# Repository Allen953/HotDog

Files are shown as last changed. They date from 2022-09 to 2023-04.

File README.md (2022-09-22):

# HotDog
HotDog is a open source quadruped robot.

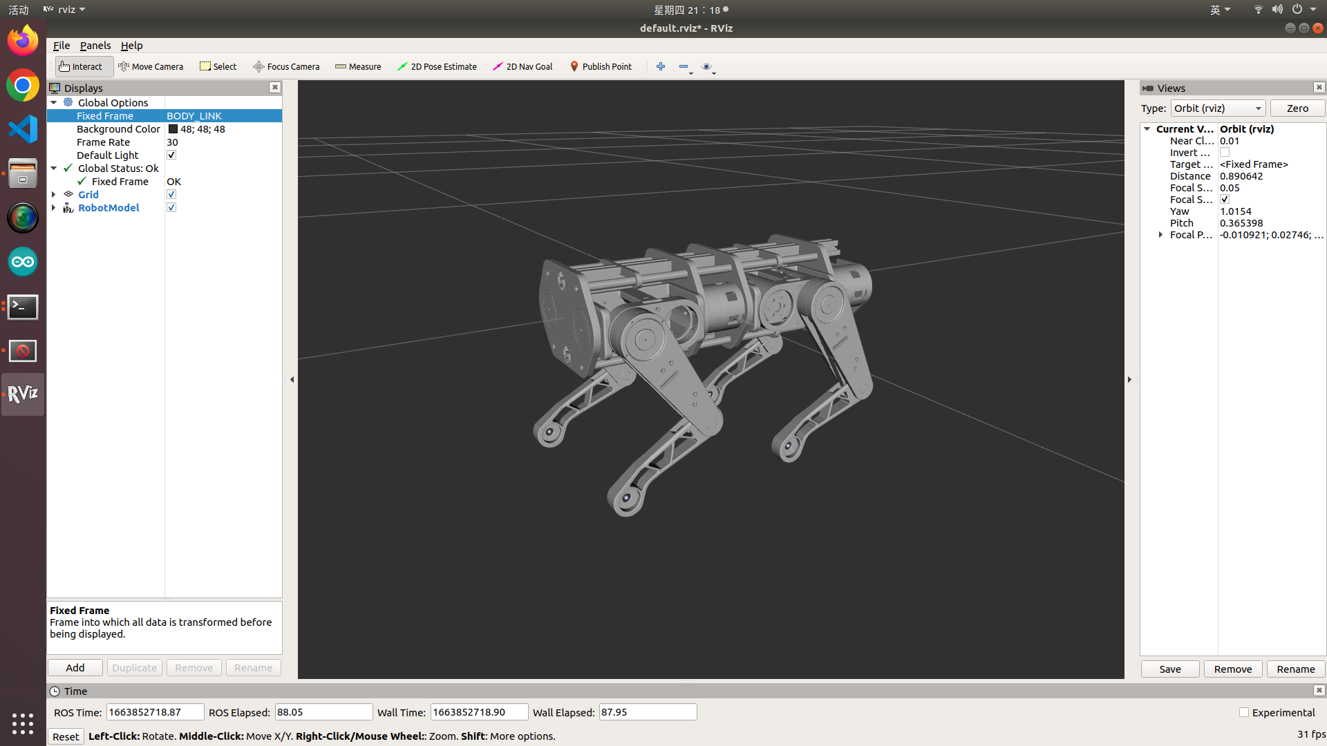
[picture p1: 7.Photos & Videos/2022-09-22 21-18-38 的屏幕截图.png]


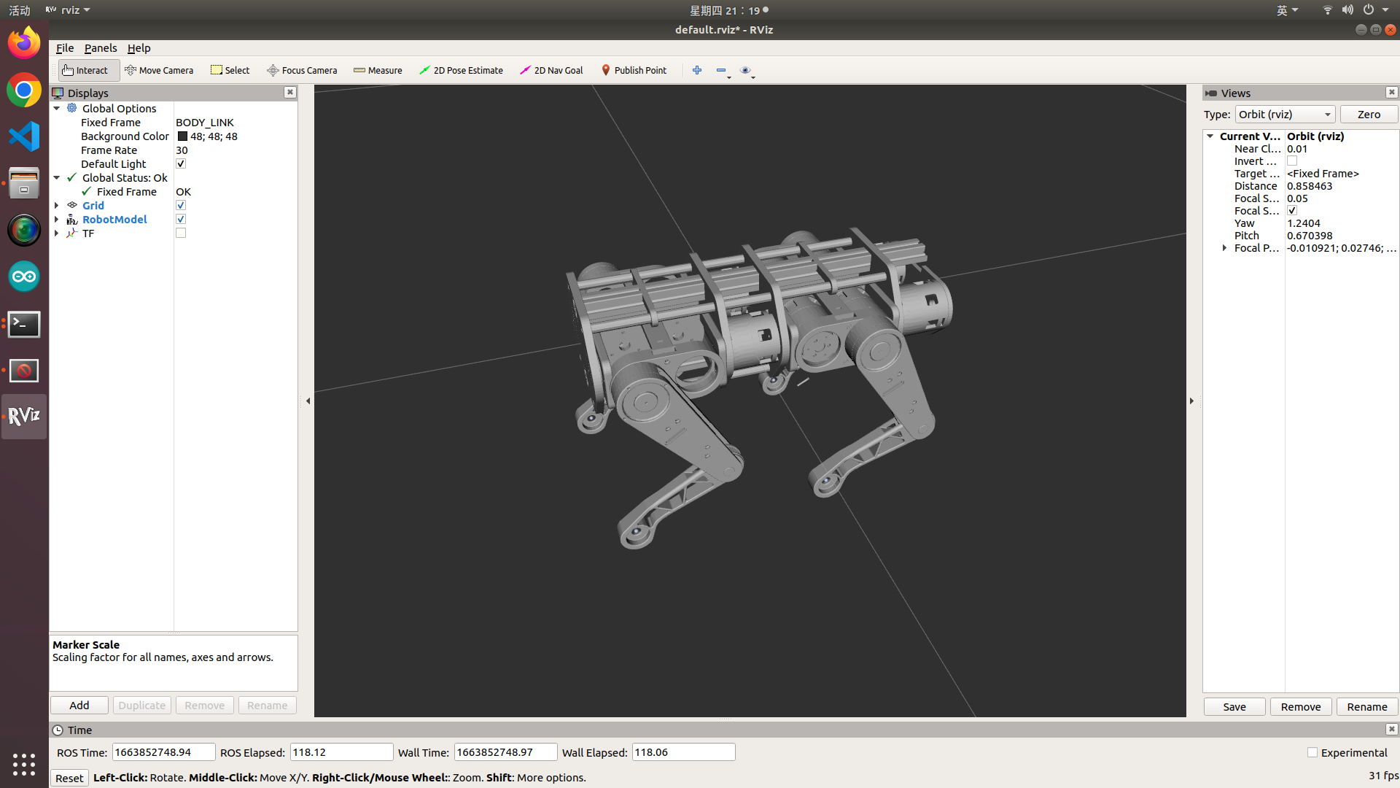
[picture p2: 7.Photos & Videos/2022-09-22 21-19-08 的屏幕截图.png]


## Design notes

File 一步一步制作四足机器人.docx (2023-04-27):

分类号 | TP242 | | | | 学校代码 | 10590
UDC | 621 | | | | 密 级 | 公开

一步一步制作四足机器人

刘志通

学 位 类 别 | 工程硕士专业学位
专 业 名 称 | 机械
学院（系、所） | 机电与控制工程学院
指 导 教 师 | 杜建铭 教授

# 第1章 四足机器人结构制作

## 1.1 引言

四足机器人的结构是实现控制系统的基础，本章首先介绍了本课题设计的四足机器人的结构，接着基于该四足机器人的模型参数，对其进行运动学和动力学建模及分析。

## 1.2 四足机器人结构组装

### 1.2.1 功能需求分析

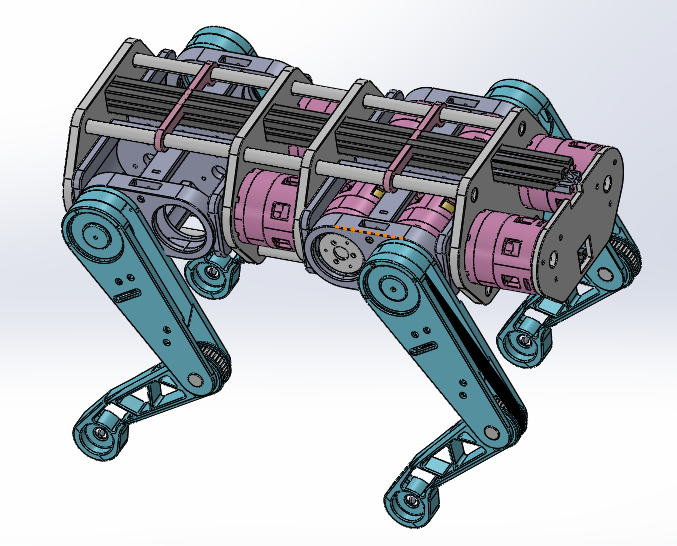
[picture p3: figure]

图1-1

机器人模型如图1-1所示，

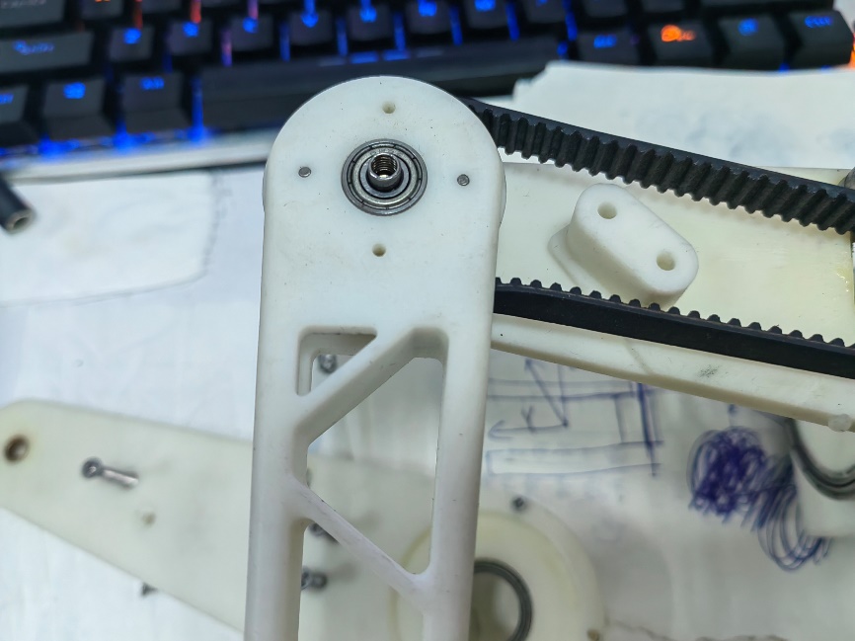
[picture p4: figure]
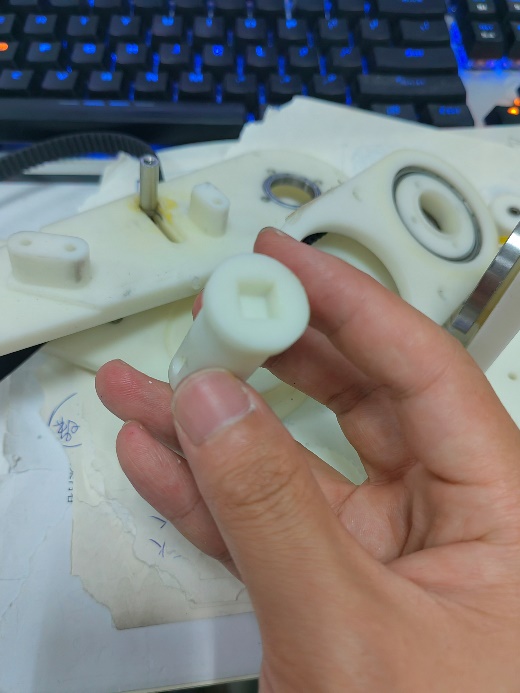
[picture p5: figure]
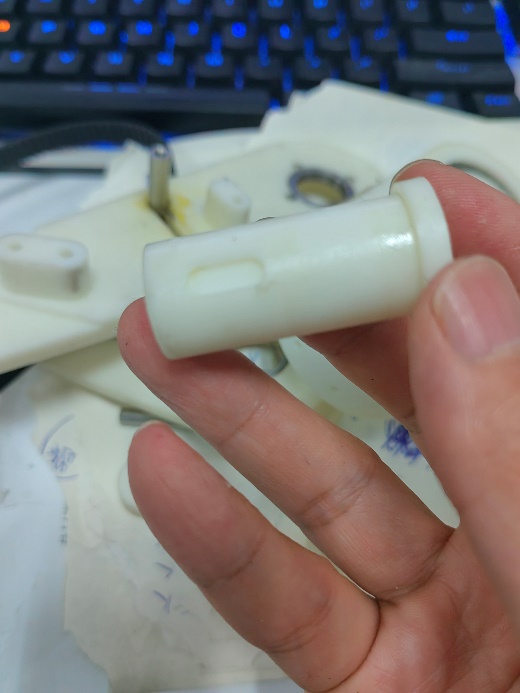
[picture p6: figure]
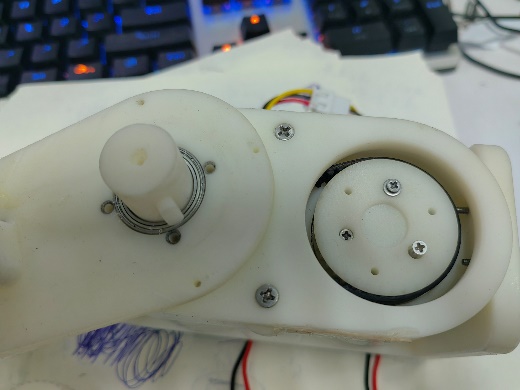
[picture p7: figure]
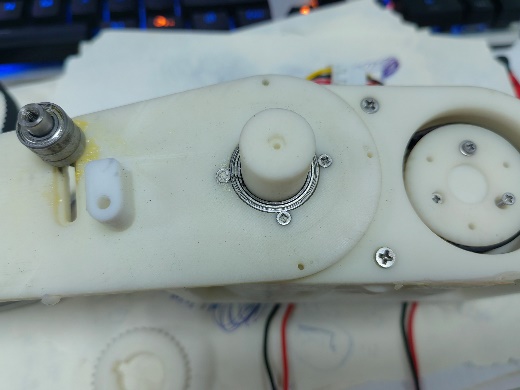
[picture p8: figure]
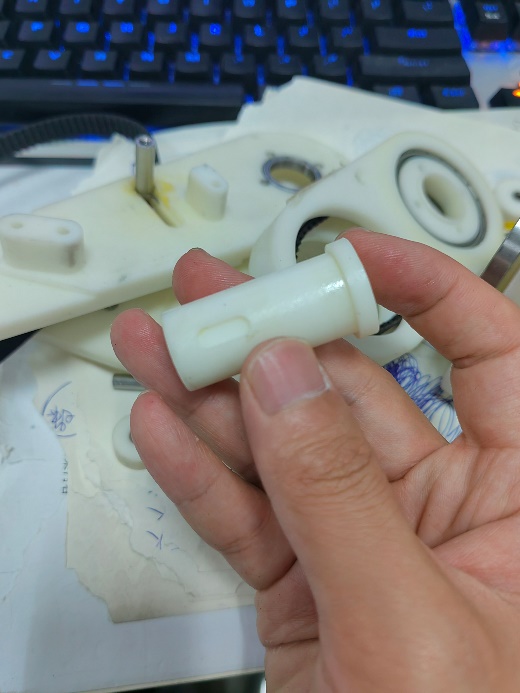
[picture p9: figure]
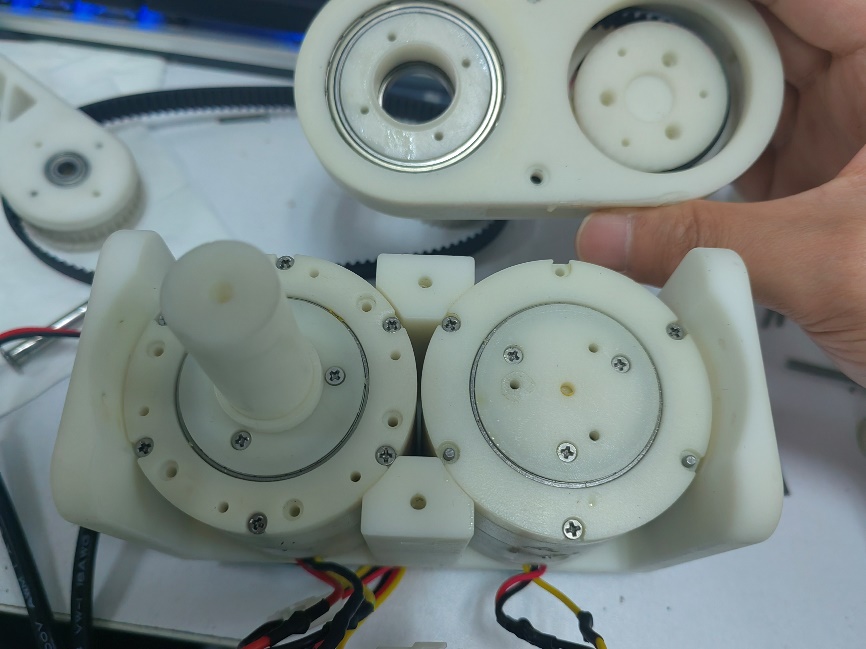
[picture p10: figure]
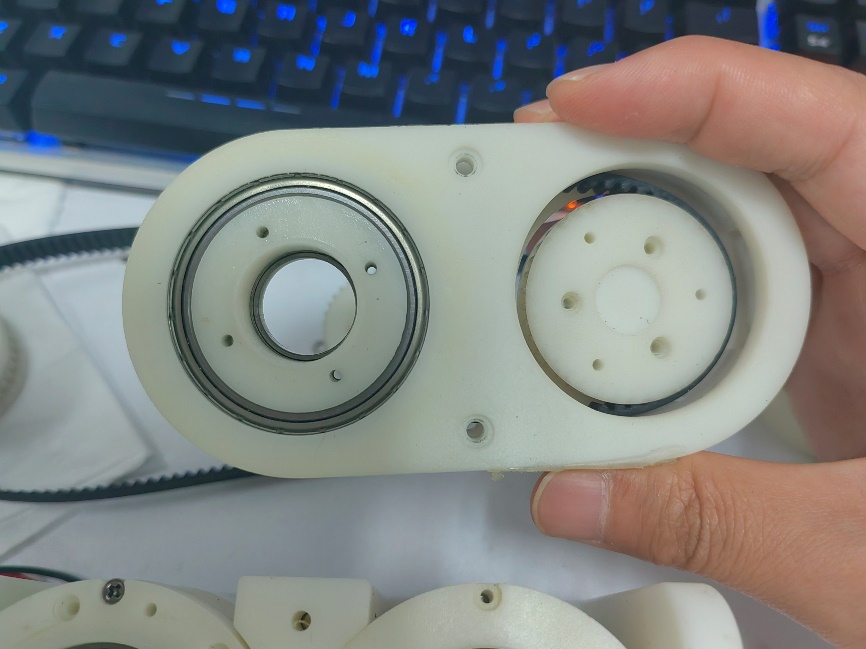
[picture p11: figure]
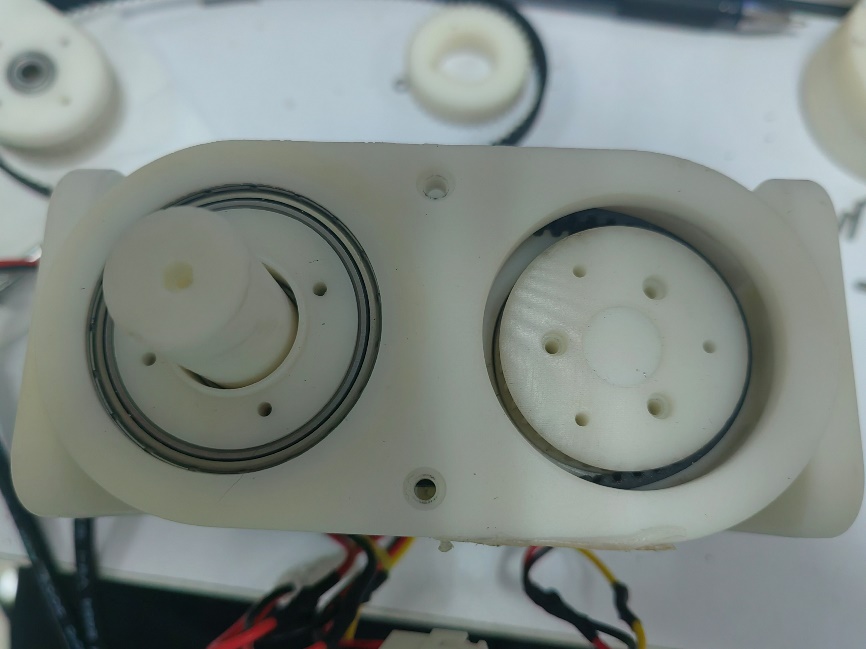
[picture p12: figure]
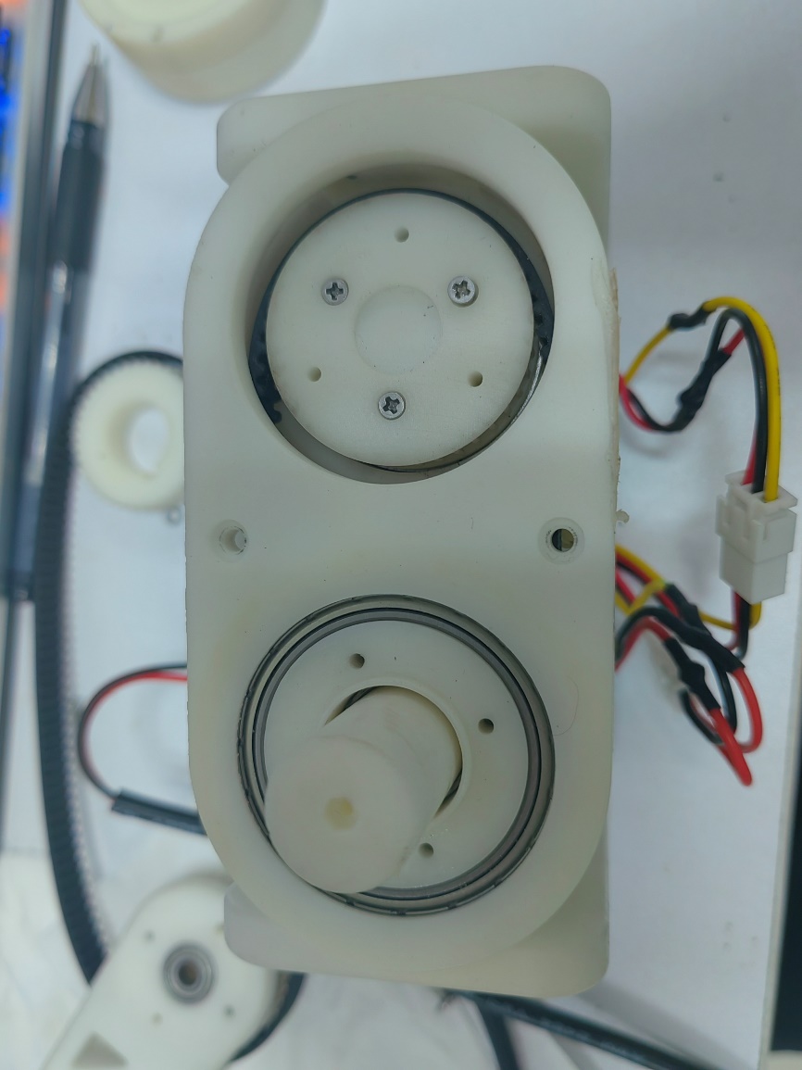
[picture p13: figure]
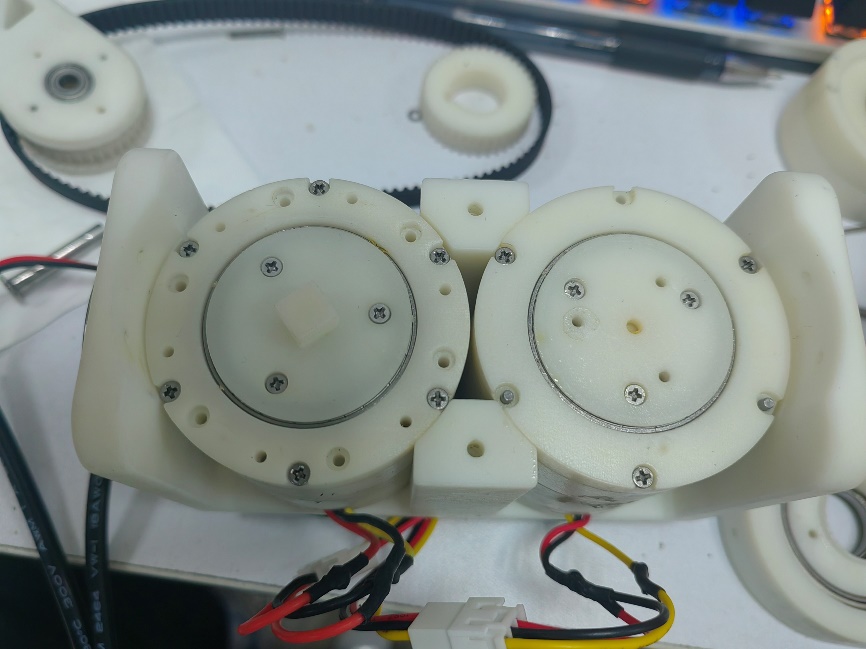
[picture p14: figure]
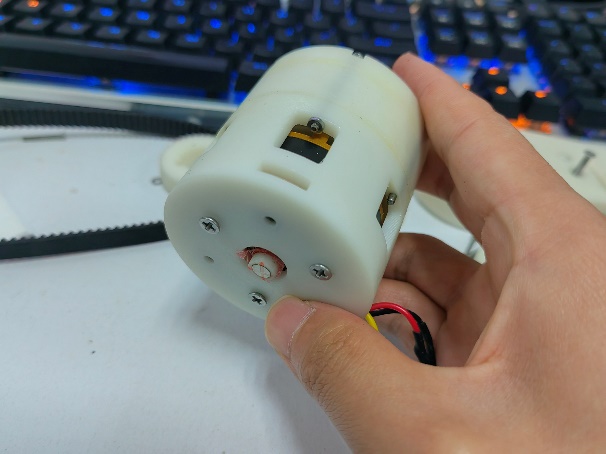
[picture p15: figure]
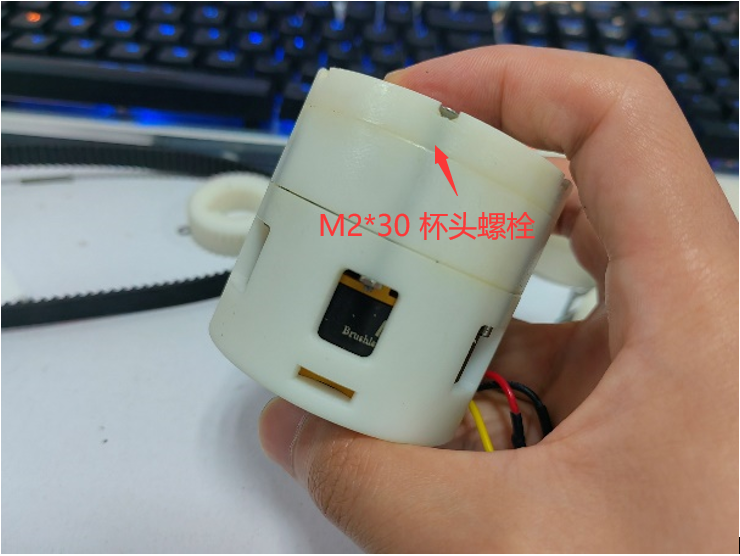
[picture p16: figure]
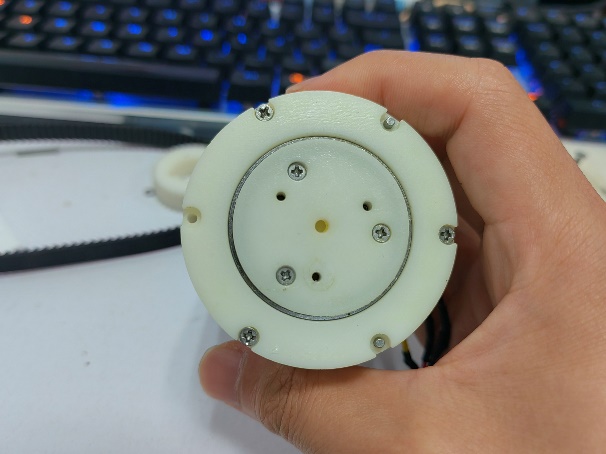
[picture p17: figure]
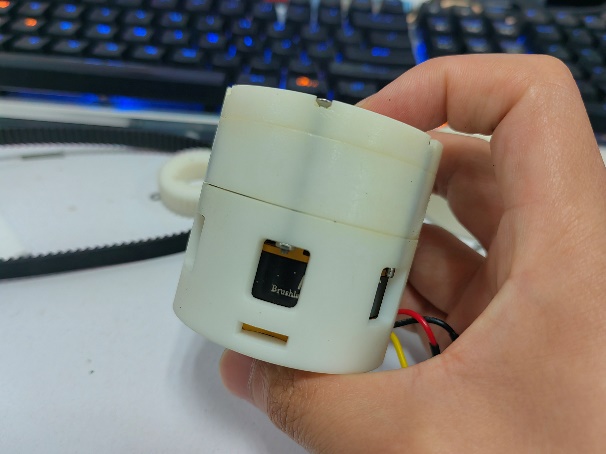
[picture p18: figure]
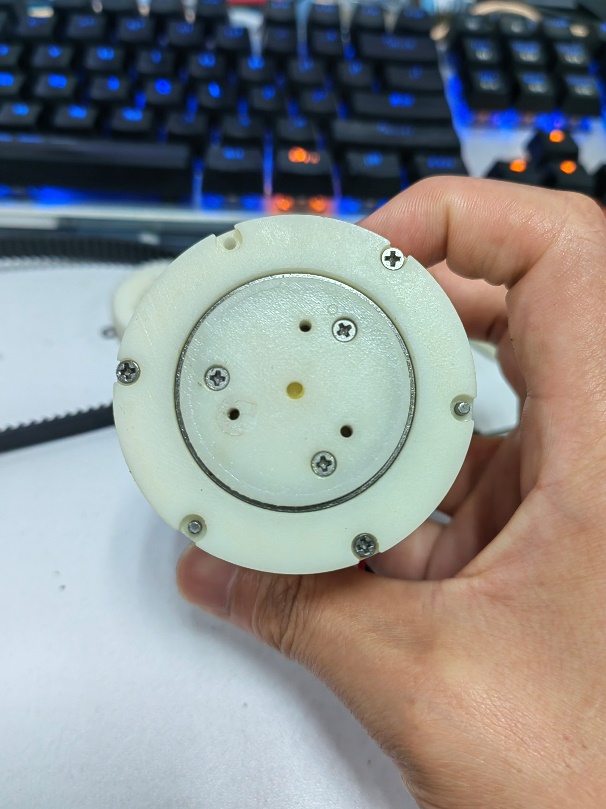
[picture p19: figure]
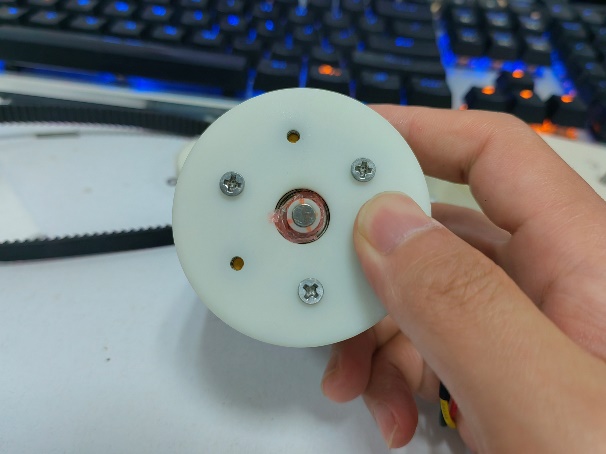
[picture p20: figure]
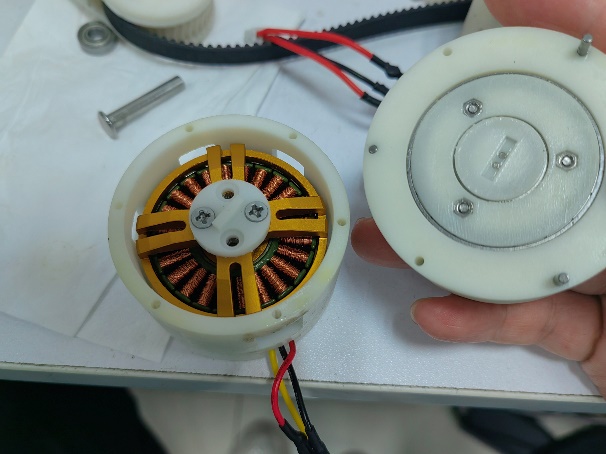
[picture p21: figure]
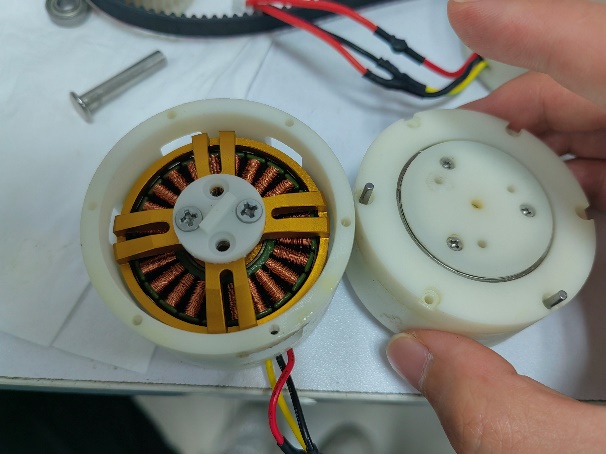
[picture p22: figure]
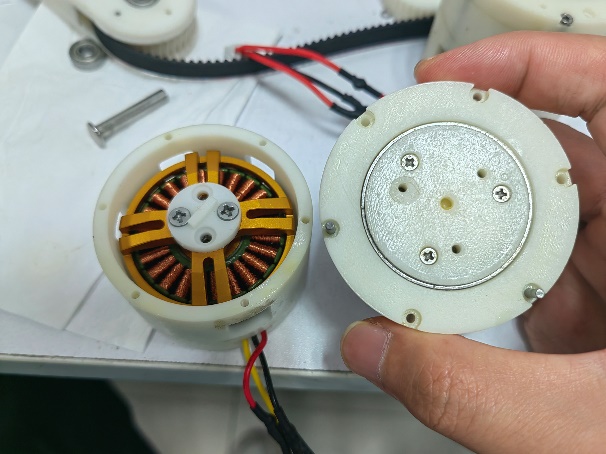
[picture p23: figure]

一个减速器需要用到的标准件：

轴承：

内30外37高4 2个

内12外18高4 1个

内8外14高4 2个

内5外11高4 1个

圆柱销：φ6*12 10个

圆柱销：φ2*18 3个

最终是一个二次型的形式，这个形式是

# 第2章 基于机器人关节学习SimpleFoc算法

## 2.1 引言

软件系统是控制系统中的核心，本章实现四足机器人ROS平台下的分布式软件系统设计。本章将分析设计软件系统架构，并基于控制软件需求设计各个核心程序，完成整个软件系统搭建。

## 2.2 SimpleFoc控制模型及流程

## 2.3 SimpleFoc实践讨论

打开HotDog项目下如下例程，研究电机的力矩控制

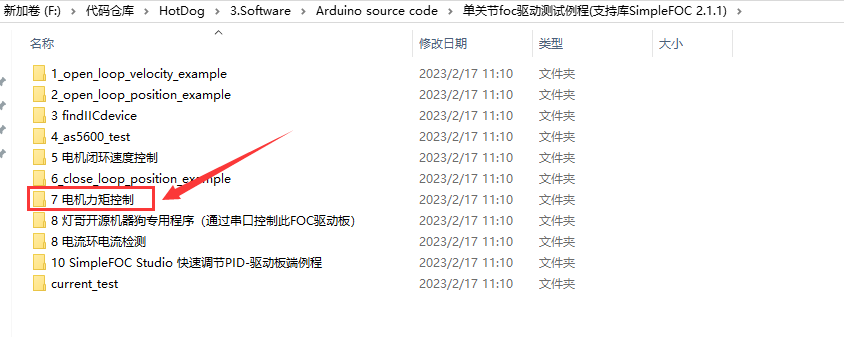
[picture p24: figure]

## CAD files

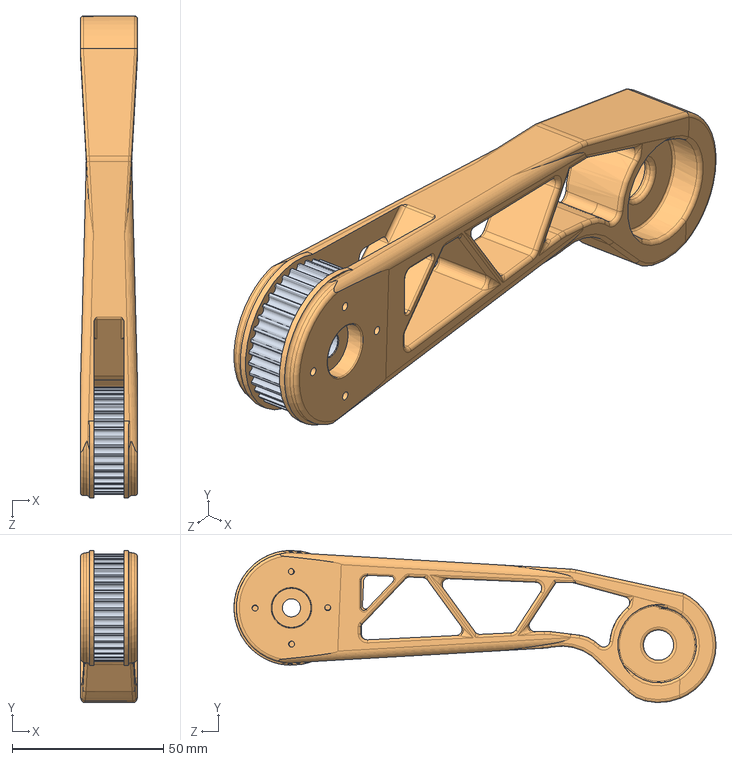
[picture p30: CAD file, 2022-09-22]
1.3D model/HotDog/RB_SHANK_LINK.SLDASM
19.0 x 50.3 x 159.4 mm
同步轮
小足

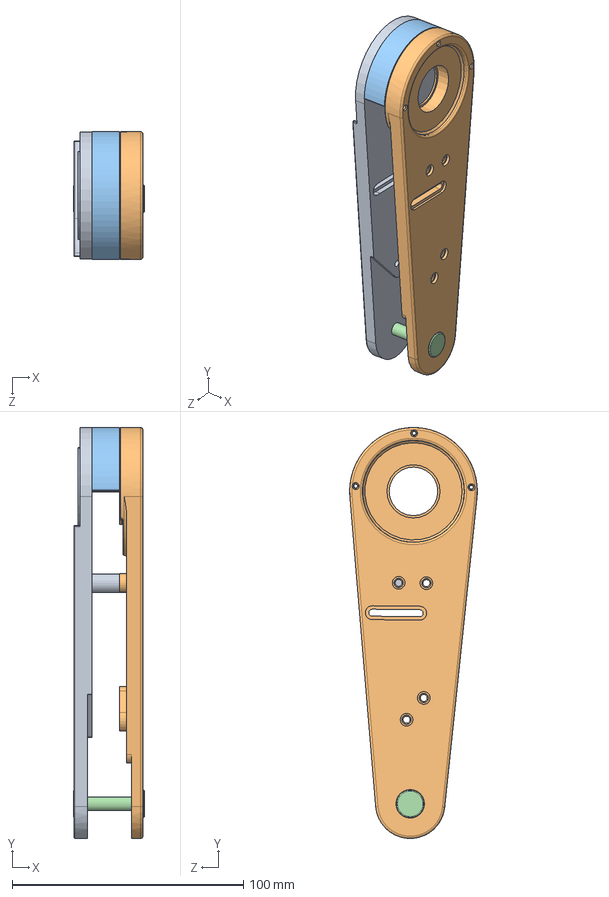
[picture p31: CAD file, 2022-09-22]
1.3D model/HotDog/RB_THIGH_LINK.SLDASM
30.6 x 177.6 x 55.2 mm
大足
大足2
支撑半环
字母钉

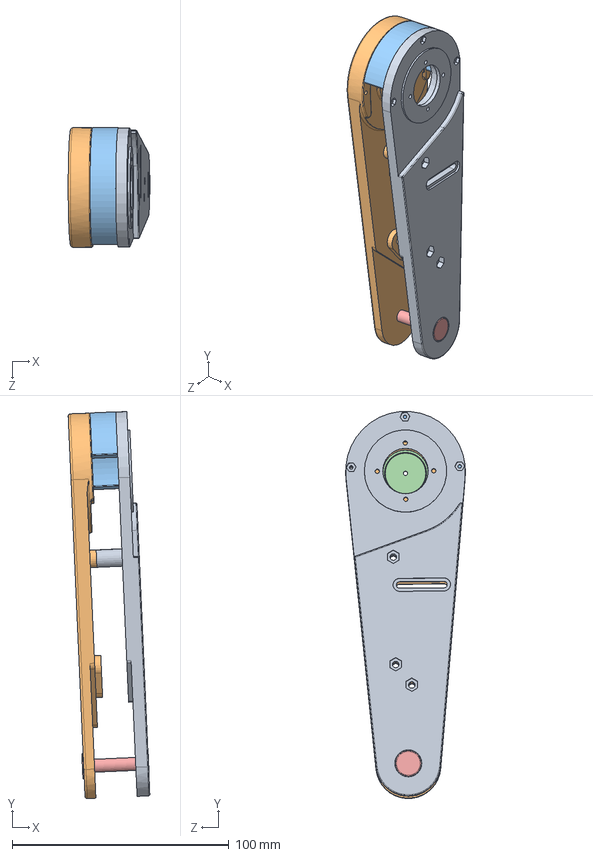
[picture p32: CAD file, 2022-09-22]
1.3D model/HotDog/LF_THIGH_LINK.SLDASM
37.6 x 178.4 x 55.2 mm
大足
大足2
支撑半环
端盖
字母钉

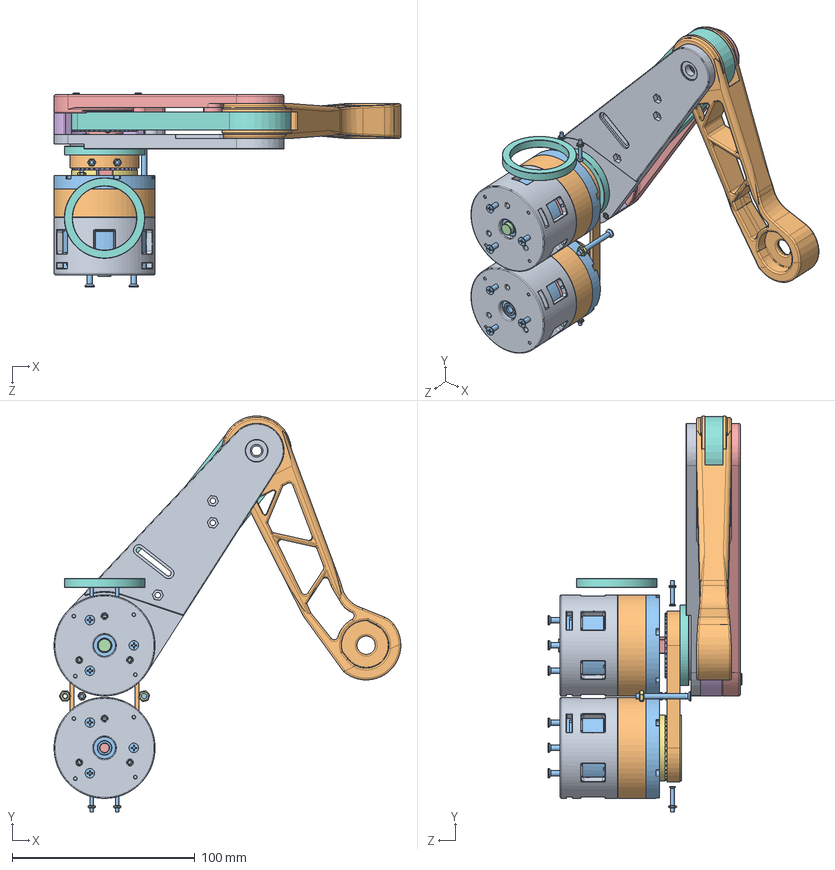
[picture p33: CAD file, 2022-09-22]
1.3D model/HotDog/关节5_0版本.SLDASM
189.6 x 216.4 x 105.8 mm
电机座 x 2
减速器壳体 x 2
30-37-4轴承6 x 2
输出轴 x 2
减速器上盖
光杆同步轮10
17-23-4轴承 x 3
35-44-5轴承 x 2
大足
小足
光杆同步轮
键
大足2
同步轮
张紧轮
端盖
cross countersunk head screw_as x 4
cross recessed countersunk head screws gb1 x 16
hex thin nuts-grades ab-chamfered gb x 4
定位环
支撑半环
hex nuts, style 1-grades ab gb x 6
同步带
定位环_17_20_1-2mm
同步带168
电机46 x 2
磁铁

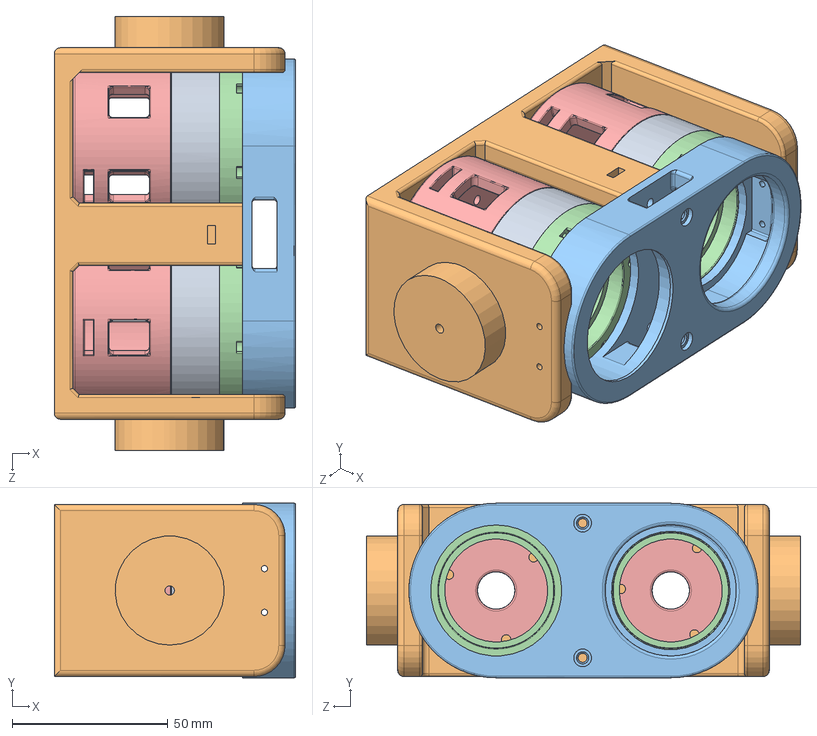
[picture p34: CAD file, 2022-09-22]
1.3D model/HotDog/RB_JIAN_LINK.SLDASM
77.4 x 56.0 x 139.2 mm
减速器壳体 x 2
支撑架
保持架
减速器上盖 x 2
电机座 x 2

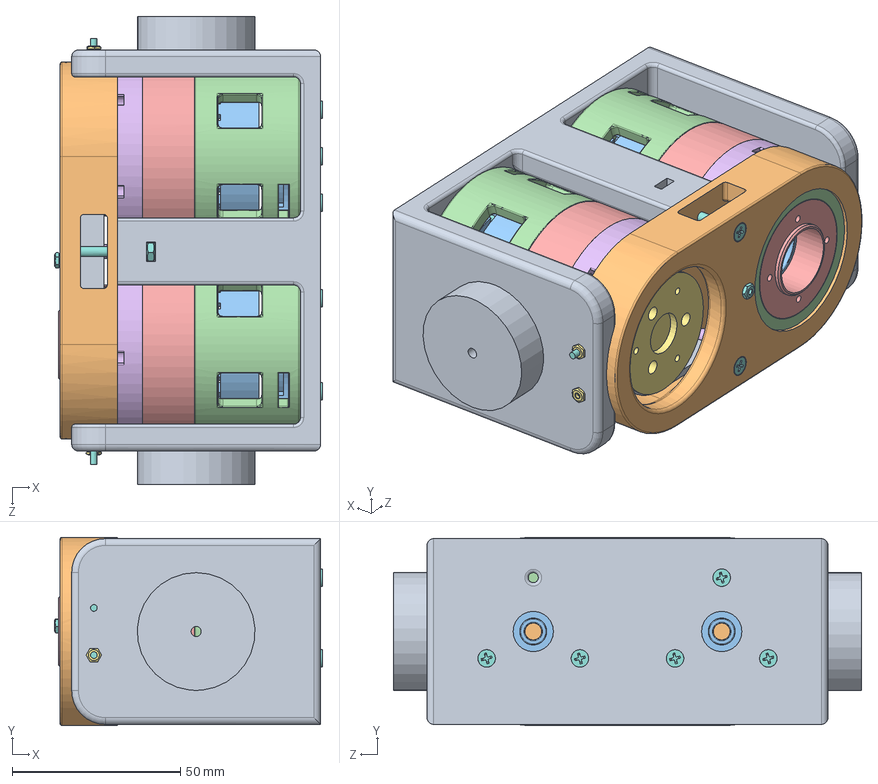
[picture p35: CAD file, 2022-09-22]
1.3D model/HotDog/LB_JIAN_LINK.SLDASM
79.7 x 56.0 x 139.2 mm
支撑架
保持架
电机46 x 2
电机座 x 2
减速器壳体 x 2
减速器上盖 x 2
cross recessed countersunk head screws gb1 x 14
30-37-4轴承6 x 2
输出轴 x 2
17-23-4轴承
35-44-5轴承
光杆同步轮10
张紧轮
hex thin nuts-grades ab-chamfered gb x 3
hex nuts, style 1-grades ab gb x 4
同步带168

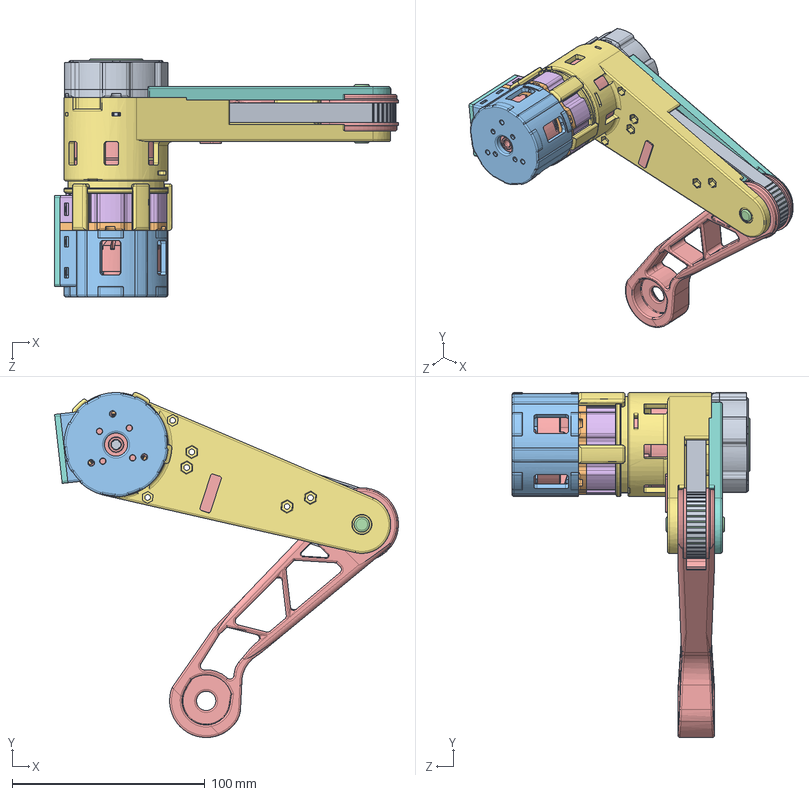
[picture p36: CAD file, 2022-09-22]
1.3D model/HotDog/Cycloid_Reducer.SLDASM
178.4 x 178.9 x 123.3 mm
机壳
轴承20_27_4 x 4
M6x10销钉 x 10
Output_Shaft2
M2x18销钉 x 5
定位中间件 x 2
轴承8_16_4
传动曲轴_2 x 2
轴承10_15_4 x 2
摆线轮1
摆线轮2
M1.5x14销轴 x 2
无刷电机 x 2
AS5600 Magntic encoder
电机架
同步轮10mm
同步带
外端盖
电机架 - 副本
同步轮10mm - 副本 (2)
狗腿子1_1
机壳 - 副本
输出盘
轴承35-44-5
连轴1 x 2
轴承9-20-6
轴套5-7-4 x 2
字母钉
轴承5-13-4 x 2
联轴件2
狗腿子盖
输入轴F
输入轴F2
链接双头螺母3-6-20
cross recessed ctsk head screws type b gb x 2
盖板 x 2
轴套6-8-15
卡口 x 3
连接板
外端盖00

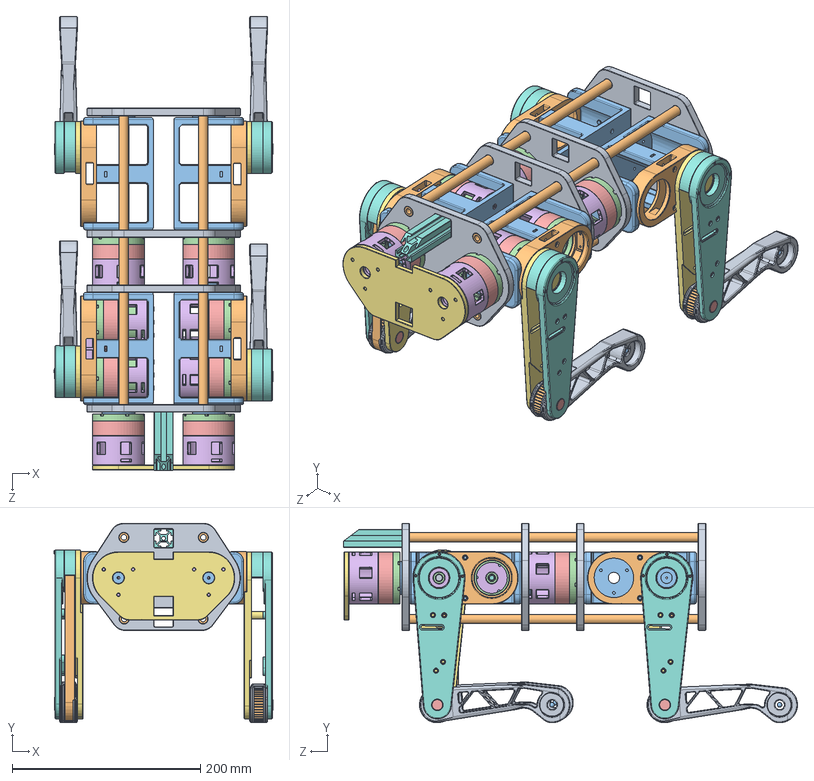
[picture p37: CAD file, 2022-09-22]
1.3D model/HotDog/四足机器人HotDog.SLDASM
232.5 x 212.0 x 482.5 mm
身躯架1 x 4
碳纤维杆10mm x 4
35-44-5轴承 x 4
减速器上盖 x 8
减速器壳体 x 8
电机座 x 8
后端板
2020铝-70
磁铁
保持架 x 4
支撑架 x 4
电机46 x 2
cross recessed countersunk head screws gb1 x 19
30-37-4轴承6 x 2
输出轴 x 2
17-23-4轴承 x 3
光杆同步轮10
张紧轮
hex thin nuts-grades ab-chamfered gb x 3
hex nuts, style 1-grades ab gb x 5
同步带168
大足 x 4
大足2 x 4
光杆同步轮
同步带
端盖 x 2
cross countersunk head screw_as x 4
字母钉 x 4
定位环_17_20_1-2mm
定位环
支撑半环 x 4
小足 x 4
同步轮 x 4
Virtual_part x 12

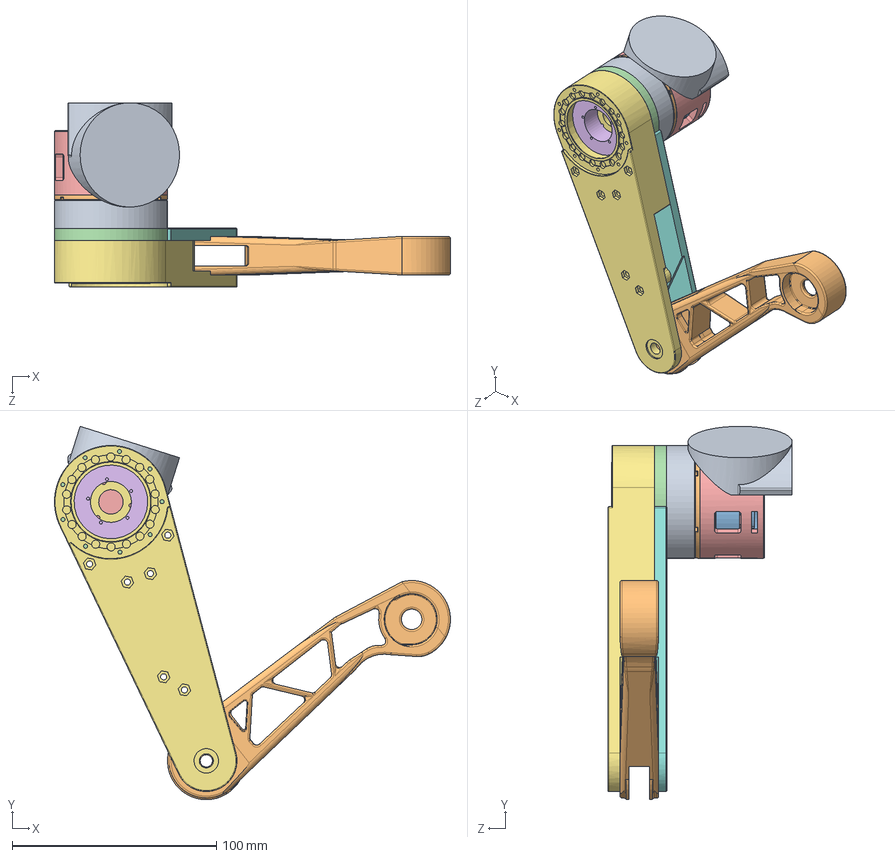
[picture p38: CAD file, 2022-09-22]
1.3D model/HotDog/装配体1.SLDASM
193.7 x 182.6 x 90.2 mm
机壳_1
零件5
30-37-4轴承 x 2
零件7
零件9
铜套10-12-6
铜套4-8-4
输入轴1级
输入轴
摆轮F x 2
键

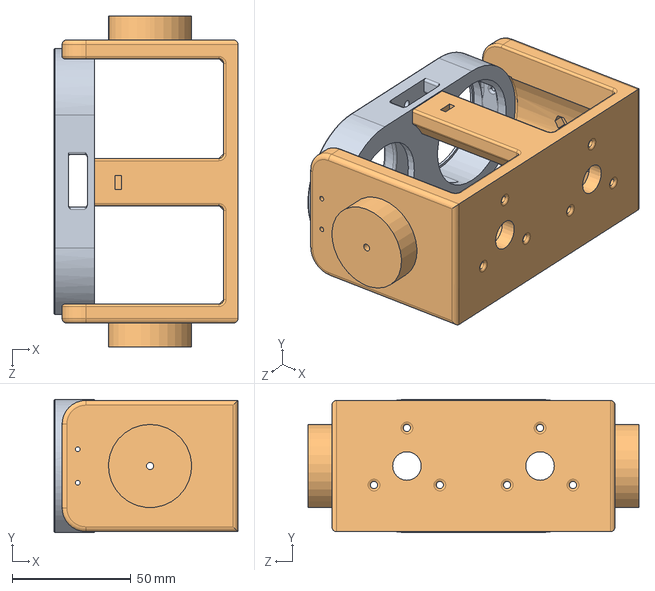
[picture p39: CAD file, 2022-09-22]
1.3D model/HotDog/LF_JIAN_LINK.SLDASM
77.4 x 56.0 x 139.2 mm
保持架
支撑架

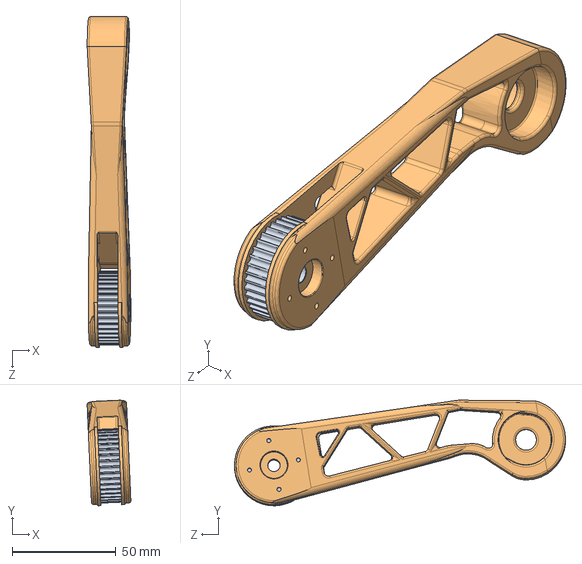
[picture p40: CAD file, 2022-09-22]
1.3D model/HotDog/LF_SHANK_LINK.SLDASM
21.1 x 50.9 x 159.3 mm
同步轮
小足

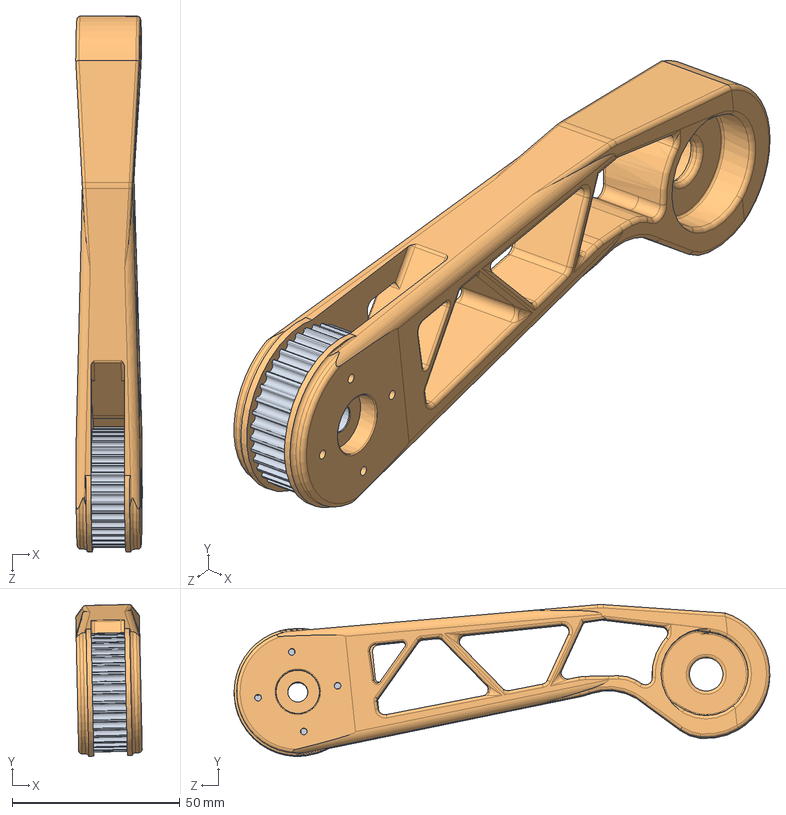
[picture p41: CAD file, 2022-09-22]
1.3D model/HotDog/RF_SHANK_LINK.SLDASM
19.9 x 45.4 x 159.9 mm
同步轮
小足

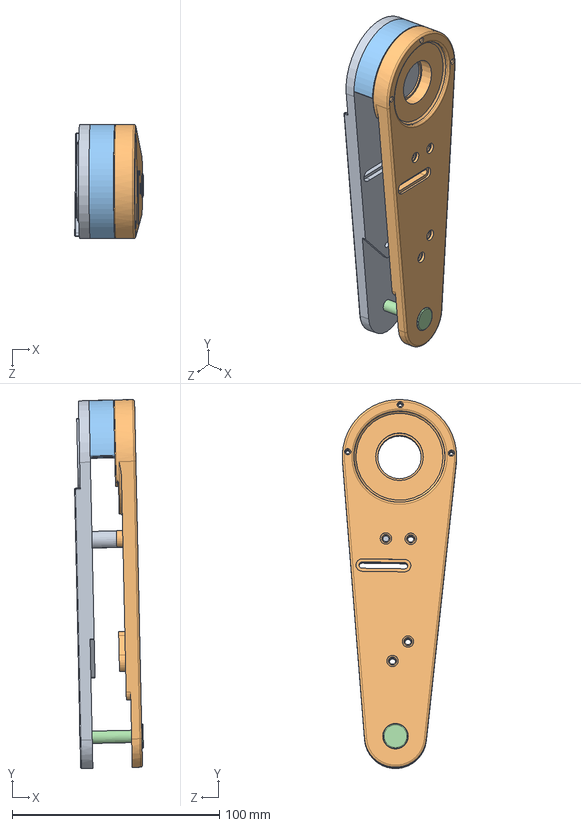
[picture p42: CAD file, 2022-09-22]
1.3D model/HotDog/RF_THIGH_LINK.SLDASM
33.2 x 178.1 x 55.2 mm
大足
大足2
支撑半环
字母钉

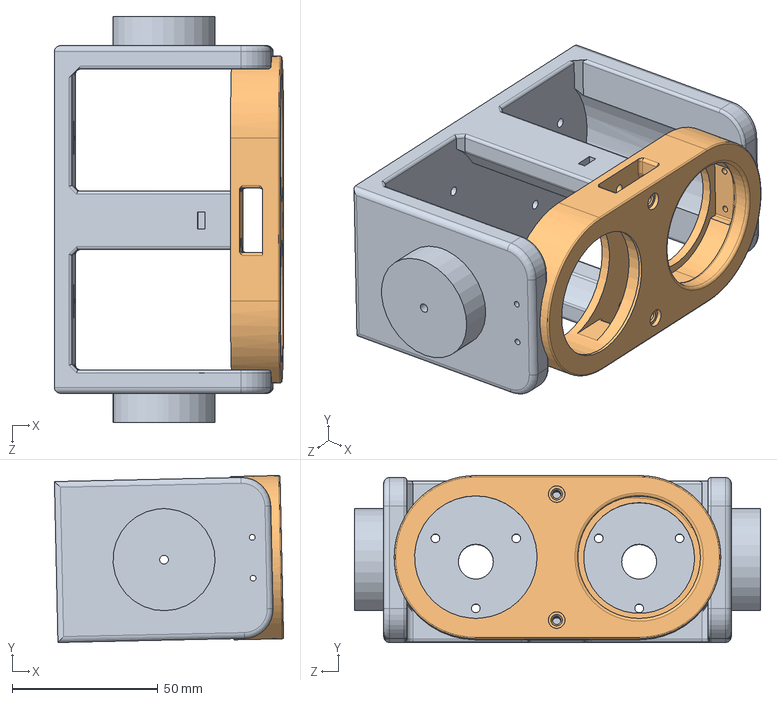
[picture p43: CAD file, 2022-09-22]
1.3D model/HotDog/RF_JIAN_LINK.SLDASM
78.6 x 57.3 x 139.2 mm
支撑架
保持架

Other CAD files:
1.3D model/HotDog/LB_SHANK_LINK.SLDASM
1.3D model/HotDog/LB_THIGH_LINK.SLDASM
1.3D model/HotDog/定位环_17_20_1-2mm.SLDPRT
1.3D model/HotDog/111.SLDPRT
1.3D model/HotDog/17-23-4轴承.SLDPRT
1.3D model/HotDog/2020铝-70.SLDPRT
1.3D model/HotDog/30-37-4轴承6.SLDPRT
1.3D model/HotDog/35-44-5轴承.SLDPRT
1.3D model/HotDog/NFS5-2020-360.0.SLDPRT
1.3D model/HotDog/Virtual_part.SLDPRT
1.3D model/HotDog/传动轴.SLDPRT
1.3D model/HotDog/保持架.SLDPRT
1.3D model/HotDog/光杆同步轮.SLDPRT
1.3D model/HotDog/光杆同步轮10.SLDPRT
1.3D model/HotDog/减速器上盖.SLDPRT
1.3D model/HotDog/减速器壳体.SLDPRT
1.3D model/HotDog/同步带.SLDPRT
1.3D model/HotDog/同步带168.SLDPRT
1.3D model/HotDog/同步轮.SLDPRT
1.3D model/HotDog/后端板.SLDPRT
1.3D model/HotDog/固定桁架.SLDPRT
1.3D model/HotDog/大足.SLDPRT
1.3D model/HotDog/大足2.SLDPRT
1.3D model/HotDog/字母钉.SLDPRT
1.3D model/HotDog/定位环.SLDPRT
1.3D model/HotDog/小足.SLDPRT
1.3D model/HotDog/张紧轮.SLDPRT
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

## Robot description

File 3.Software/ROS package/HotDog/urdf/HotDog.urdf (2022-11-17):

<?xml version="1.0" encoding="utf-8"?>
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
<robot name="HotDog">
  <link name="BODY_LINK">
    <inertial>
      <origin xyz="-0.0371687442236052 0.00016322891231972 -5.50209374861353E-05" rpy="0 0 0" />
      <mass value="1.06660031766174" />
      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
    </inertial>
    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
  </link>
  <link name="LF_JIAN_LINK">
    <inertial>
      <origin xyz="-0.000741533210672114 -4.7995835830289E-06 -0.028405263004785" rpy="0 0 0" />
      <mass value="0.164648707873323" />
      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
    </inertial>
    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
  </link>
  <joint name="LF_JIAN_JOINT" type="revolute">
    <origin xyz="0.1199 0.04805 -0.001" rpy="1.5708 0 1.5708" />
    <parent link="BODY_LINK" />
    <child link="LF_JIAN_LINK" />
    <axis xyz="0 0 1" />
    <limit lower="-1.5708" upper="1.5708" effort="0" velocity="0" />
  </joint>
  <link name="LF_THIGH_LINK">
    <inertial>
      <origin xyz="0.0508525846899987 -0.00075850600525168 -5.73760741986035E-05" rpy="0 0 0" />
      <mass value="0.0986910738752765" />
      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
    </inertial>
    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
  </link>
  <joint name="LF_THIGH_JOINT" type="revolute">
    <origin xyz="0.05305 0 0" rpy="-1.5708 0.023282 -1.5708" />
    <parent link="LF_JIAN_LINK" />
    <child link="LF_THIGH_LINK" />
    <axis xyz="0 0 -1" />
    <limit lower="-1.5708" upper="1.5708" effort="0" velocity="0" />
  </joint>
  <link name="LF_SHANK_LINK">
    <inertial>
      <origin xyz="0.0524852485214341 -0.0020157518410453 4.12966244767166E-06" rpy="0 0 0" />
      <mass value="0.0485389866008694" />
      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
    </inertial>
    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
  </link>
  <joint name="LF_SHANK_JOINT" type="revolute">
    <origin xyz="0.13499 -0.0012933 0" rpy="0 0 -1.5941" />
    <parent link="LF_THIGH_LINK" />
    <child link="LF_SHANK_LINK" />
    <axis xyz="0 0 -1" />
    <limit lower="-1.5708" upper="1.5708" effort="0" velocity="0" />
  </joint>
  <link name="LF_R_LINK">
    <inertial>
      <origin xyz="-2.77555756156289E-17 0 0" rpy="0 0 0" />
      <mass value="6.54498469497874E-05" />
      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
    </inertial>
    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
  </link>
  <joint name="LF_R_JOINT" type="revolute">
    <origin xyz="0.122 0 0" rpy="1.5708 0 0" />
    <parent link="LF_SHANK_LINK" />
    <child link="LF_R_LINK" />
    <axis xyz="0 0 -1" />
    <limit lower="-1.5708" upper="1.5708" effort="0" velocity="0" />
  </joint>
  <link name="LF_P_LINK">
    <inertial>
      <origin xyz="0 0 -2.77555756156289E-17" rpy="0 0 0" />
      <mass value="6.54498469497874E-05" />
      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
    </inertial>
    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
  </link>
  <joint name="LF_P_JOINT" type="revolute">
    <origin xyz="0 0 0" rpy="0 1.5708 0" />
    <parent link="LF_R_LINK" />
    <child link="LF_P_LINK" />
    <axis xyz="0 0 -1" />
    <limit lower="-1.5708" upper="1.5708" effort="0" velocity="0" />
  </joint>
  <link name="LF_Y_LINK">
    <inertial>
      <origin xyz="0 -2.77555756156289E-17 0" rpy="0 0 0" />
      <mass value="6.54498469497874E-05" />
      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
    </inertial>
    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
  </link>
  <joint name="LF_Y_JOINT" type="revolute">
    <origin xyz="0 0 0" rpy="1.5708 0 0" />
    <parent link="LF_P_LINK" />
    <child link="LF_Y_LINK" />
    <axis xyz="0 0 1" />
    <limit lower="-1.5708" upper="1.5708" effort="0" velocity="0" />
  </joint>
  <link name="LB_JIAN_LINK">
    <inertial>
      <origin xyz="0.00111242445505096 6.9888123392964E-05 -0.0282503390893783" rpy="0 0 0" />
      <mass value="0.326912693320869" />
      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
    </inertial>
    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
  </link>
  <joint name="LB_JIAN_JOINT" type="revolute">
    <origin xyz="-0.1219 0.04805 -0.001" rpy="-1.5708 0 1.5708" />
    <parent link="BODY_LINK" />
    <child link="LB_JIAN_LINK" />
    <axis xyz="0 0 -1" />
    <limit lower="-1.5708" upper="1.5708" effort="0" velocity="0" />
  </joint>
  <link name="LB_THIGH_LINK">
    <inertial>
      <origin xyz="0.0434722231723628 -0.000195922727933742 -0.00150945945314165" rpy="0 0 0" />
      <mass value="0.126723876610191" />
      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
    </inertial>
    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
  </link>
  <joint name="LB_THIGH_JOINT" type="revolute">
    <origin xyz="0.05305 -0.0022197 -0.0034125" rpy="1.5708 -0.013702 1.5708" />
    <parent link="LB_JIAN_LINK" />
    <child link="LB_THIGH_LINK" />
    <axis xyz="0 0 1" />
    <limit lower="-1.5708" upper="1.5708" effort="0" velocity="0" />
  </joint>
  <link name="LB_SHANK_LINK">
    <inertial>
      <origin xyz="0.052523902247848 -7.14126603541809E-05 4.13478116592647E-06" rpy="0 0 0" />
      <mass value="0.0485390257312316" />
      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
    </inertial>
    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
  </link>
  <joint name="LB_SHANK_JOINT" type="revolute">
    <origin xyz="0.135 0 0" rpy="0 0 -1.6215" />
    <parent link="LB_THIGH_LINK" />
    <child link="LB_SHANK_LINK" />
    <axis xyz="0 0 -1" />
    <limit lower="-1.5708" upper="1.5708" effort="0" velocity="0" />
  </joint>
  <link name="LB_R_LINK">
    <inertial>
      <origin xyz="-1.73472347597681E-18 0 0" rpy="0 0 0" />
      <mass value="6.54498469497874E-05" />
      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
    </inertial>
    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
  </link>
  <joint name="LB_R_JOINT" type="revolute">
    <origin xyz="0.12192 0.0045163 0" rpy="1.5708 0 0.037028" />
    <parent link="LB_SHANK_LINK" />
    <child link="LB_R_LINK" />
    <axis xyz="0 0 -1" />
    <limit lower="-1.5708" upper="1.5708" effort="0" velocity="0" />
  </joint>
  <link name="LB_P_LINK">
    <inertial>
      <origin xyz="0 0 -1.73472347597681E-18" rpy="0 0 0" />
      <mass value="6.54498469497874E-05" />
      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
    </inertial>
    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
  </link>
  <joint name="LB_P_JOINT" type="revolute">
    <origin xyz="0 0 0" rpy="0 1.5708 0" />
    <parent link="LB_R_LINK" />
    <child link="LB_P_LINK" />
    <axis xyz="0 0 -1" />
    <limit lower="-1.5708" upper="1.5708" effort="0" velocity="0" />
  </joint>
  <link name="LB_Y_LINK">
    <inertial>
      <origin xyz="0 -1.73472347597681E-18 0" rpy="0 0 0" />
      <mass value="6.54498469497874E-05" />
      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
    </inertial>
    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
  </link>
  <joint name="LB_Y_JOINT" type="revolute">
    <origin xyz="0 0 0" rpy="1.5708 0 0" />
    <parent link="LB_P_LINK" />
    <child link="LB_Y_LINK" />
    <axis xyz="0 0 1" />
    <limit lower="-1.5708" upper="1.5708" effort="0" velocity="0" />
  </joint>
  <link name="RF_JIAN_LINK">
    <inertial>
      <origin xyz="-0.000741503529284405 9.43071581690798E-06 -0.0276445307185166" rpy="0 0 0" />
      <mass value="0.164648707873323" />
      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
    </inertial>
    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
  </link>
  <joint name="RF_JIAN_JOINT" type="revolute">
    <origin xyz="0.1199 -0.04795 -0.001" rpy="-1.5708 0.021756 -1.5708" />
    <parent link="BODY_LINK" />
    <child link="RF_JIAN_LINK" />
    <axis xyz="0 0 1" />
    <limit lower="-1.5708" upper="1.5708" effort="0" velocity="0" />
  </joint>
  <link name="RF_THIGH_LINK">
    <inertial>
      <origin xyz="0.0512196578451125 0.00078015605506318 0.000191818707834981" rpy="0 0 0" />
      <mass value="0.0976231637562044" />
      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
    </inertial>
    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
  </link>
  <joint name="RF_THIGH_JOINT" type="revolute">
    <origin xyz="0.053037 -0.001 0" rpy="-1.5708 -0.00052673 1.549" />
    <parent link="RF_JIAN_LINK" />
    <child link="RF_THIGH_LINK" />
    <axis xyz="0.021754 0 -0.99976" />
    <limit lower="-1.5708" upper="1.5708" effort="0" velocity="0" />
  </joint>
  <link name="RF_SHANK_LINK">
    <inertial>
      <origin xyz="0.0524852553396524 -0.00201575621178718 4.13470284280071E-06" rpy="0 0 0" />
      <mass value="0.0485390235838856" />
      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
    </inertial>
    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
  </link>
  <joint name="RF_SHANK_JOINT" type="revolute">
    <origin xyz="0.13483 0.0019208 0" rpy="0 0 -1.5703" />
    <parent link="RF_THIGH_LINK" />
    <child link="RF_SHANK_LINK" />
    <axis xyz="0 0 -1" />
    <limit lower="-1.5708" upper="1.5708" effort="0" velocity="0" />
  </joint>
  <link name="RF_R_LINK">
    <inertial>
      <origin xyz="-2.77555756156289E-17 2.77555756156289E-17 -2.77555756156289E-17" rpy="0 0 0" />
      <mass value="6.54498469497874E-05" />
      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
    </inertial>
    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
  </link>
  <joint name="RF_R_JOINT" type="revolute">
    <origin xyz="0.122 0 0" rpy="1.5708 0 0" />
    <parent link="RF_SHANK_LINK" />
    <child link="RF_R_LINK" />
    <axis xyz="0 0 -1" />
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

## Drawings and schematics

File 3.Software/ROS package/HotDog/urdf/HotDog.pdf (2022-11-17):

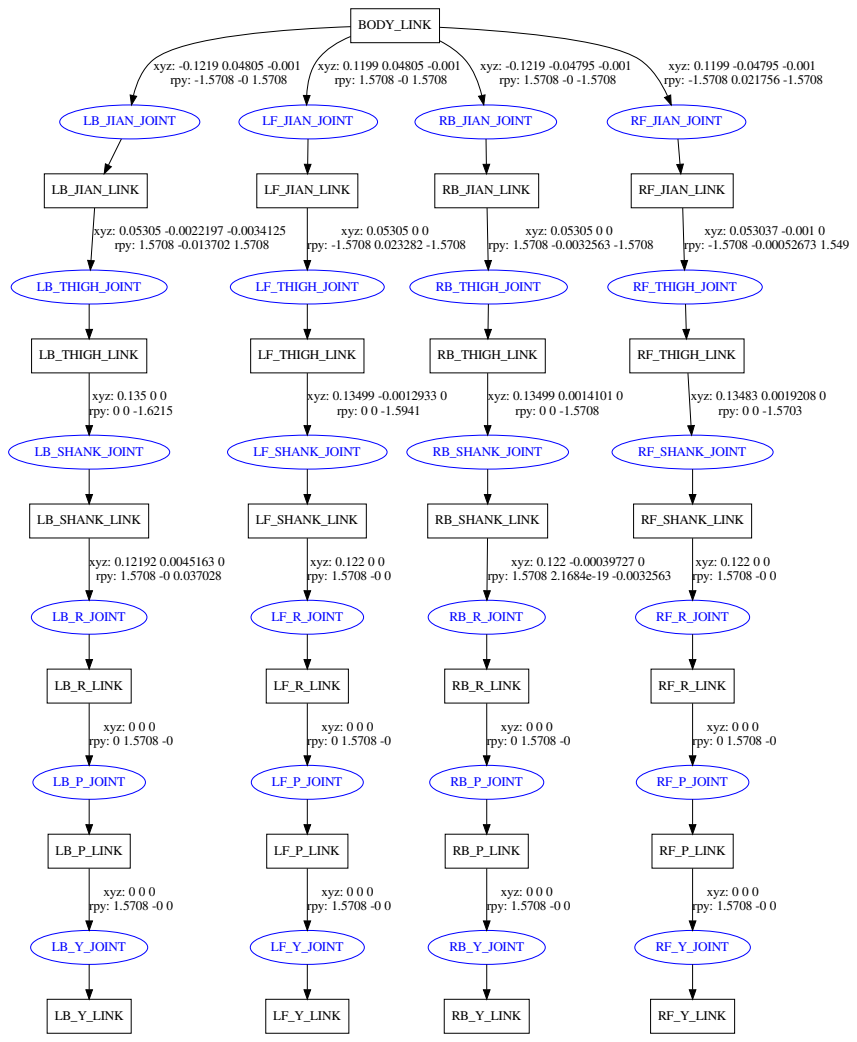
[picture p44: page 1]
BODY_LINK; LB_JIAN_JOINT; xyz: -0.1219 0.04805 -0.001 rpy: -1.5708 -0 1.5708; LF_JIAN_JOINT; xyz: 0.1199 0.04805 -0.001 rpy: 1.5708 -0 1.5708; RB_JIAN_JOINT; xyz: -0.1219 -0.04795 -0.001 rpy: 1.5708 -0 -1.5708; RF_JIAN_JOINT; xyz: 0.1199 -0.04795 -0.001 rpy: -1.5708 0.021756 -1.5708; LB_JIAN_LINK; LB_THIGH_JOINT; xyz: 0.05305 -0.0022197 -0.0034125 rpy: 1.5708 -0.013702 1.5708; LB_THIGH_LINK; LB_SHANK_JOINT; xyz: 0.135 0 0 rpy: 0 0 -1.6215; LB_SHANK_LINK; LB_R_JOINT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

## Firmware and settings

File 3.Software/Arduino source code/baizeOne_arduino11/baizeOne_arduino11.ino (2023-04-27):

// Deng's FOC 开环位置控制例程 测试库：SimpleFOC 2.1.1 测试硬件：灯哥开源FOC V1.0
// 串口中输入"T+数字"设定两个电机的位置，如设置电机转到到180度，输入 "T3.14"（弧度制的180度）
// 在使用自己的电机时，请一定记得修改默认极对数，即 BLDCMotor(7) 中的值，设置为自己的极对数数字
// 程序默认设置的供电电压为 7.4V,用其他电压供电请记得修改 voltage_power_supply , voltage_limit 变量中的值
//               FOC_0.2  Baize_Foc
// IN1     pwm1     9        17
// IN2     pwm2     6        18
// IN3     pwm3     5        19
// INH1   enable1   8        21
// INH2   enable2   7        22
// INH3   enable3   4        23
// 电机极对数:11            减速比:11
//in-line current sense - phase 1/A 35
//in-line current sense - phase 1/C 34
// ESP32  iic接口  SCL:25   SDA:26
// AS5600 iic地址: 0x36
//I2Cone.begin(sda, scl, frequency); 


#include "WiFi.h"
#include <ros.h>
#include <std_msgs/String.h>
#include <std_msgs/Int16.h>
#include <std_msgs/Float64.h>
#include <rosserial_arduino/Adc.h>
#include <robot_msg/quadrupedrobot_jointstate.h>
#include <Wire.h>
#include <SimpleFOC.h>

#define rec 2.95
#define dir 1

MagneticSensorI2C sensor = MagneticSensorI2C(AS5600_I2C);
TwoWire I2Cone = TwoWire(0);

BLDCMotor motor = BLDCMotor(11);
BLDCDriver3PWM driver = BLDCDriver3PWM(17, 19, 18, 21, 22, 23);


//目标位置
float target_position = 0;

//设置AP信息(SSID和PASSWORD)
const char* ssid = "S725";
const char* password = "s725s725";

IPAddress server(192, 168, 1, 111); // ip of your ROS server
IPAddress ip_address;
int status = WL_IDLE_STATUS;

WiFiClient client;
 
class WiFiHardware {
 
  public:
  WiFiHardware() {};
 
  void init() {
    // do your initialization here. this probably includes TCP server/client setup
    client.connect(server, 11421);
  }
 
  // read a byte from the serial port. -1 = failure
  int read() {
    // implement this method so that it reads a byte from the TCP connection and returns it
    //  you may return -1 is there is an error; for example if the TCP connection is not open
    return client.read();         //will return -1 when it will works
  }
 
  // write data to the connection to ROS
  void write(uint8_t* data, int length) {
    // implement this so that it takes the arguments and writes or prints them to the TCP connection
    for(int i=0; i<length; i++)
      client.write(data[i]);
  }
 
  // returns milliseconds since start of program
  unsigned long time() {
     return millis(); // easy; did this one for you
  }
};
 
int i;

void JointStateCallback(const robot_msg::quadrupedrobot_jointstate& jointstate) {
  motor.loopFOC();
  motor.move(jointstate.position[10]*10+rec);


  Serial.println(sensor.getAngle());
  // We can now plot text on screen using the "print" class
  delay(1);
}
 
 
std_msgs::String str_msg;
ros::Publisher chatter("BaizeJoint11", &str_msg);
ros::Subscriber<robot_msg::quadrupedrobot_jointstate> subjoint("/quadruped_joint", JointStateCallback);

ros::NodeHandle_<WiFiHardware> nh;
char hello[20] = "Joint11 alive!";
 
 
void setupWiFi()
{
  WiFi.setHostname("BaizeJoint11");
  WiFi.begin(ssid, password);
  Serial.print("\nConnecting to "); Serial.println(ssid);
  uint8_t i = 0;
  while (WiFi.status() != WL_CONNECTED && i++ < 20) delay(500);
  if(i == 21){
    Serial.print("Could not connect to"); Serial.println(ssid);
    while(1) delay(500);
  }
  Serial.print("Ready! Use ");
  Serial.print(WiFi.localIP());
  Serial.println(" to access client");
}

void setup() {
  I2Cone.begin(26, 25, 400000); 
  sensor.init(&I2Cone);
  //连接motor对象与传感器对象
  motor.linkSensor(&sensor);
  
  Serial.begin(115200);
  //供电电压设置 [V]
  driver.voltage_power_supply = 12.0;
  driver.init();

  //连接电机和driver对象
  motor.linkDriver(&driver);
  
  //FOC模型选择
  motor.foc_modulation = FOCModulationType::SpaceVectorPWM;
  //运动控制模式设置
  motor.controller = MotionControlType::angle;

  //速度PI环设置
  motor.PID_velocity.P = 0.2;
  motor.PID_velocity.I = 20;
  //角度P环设置 
  motor.P_angle.P = 20;
  //最大电机限制电机
  motor.voltage_limit = 7.4;
  
  //速度低通滤波时间常数
  motor.LPF_velocity.Tf = 0.01;

  //设置最大速度限制
  motor.velocity_limit = 60;

  motor.useMonitoring(Serial);
  
  //初始化电机
  motor.init();
  //初始化 FOC
  motor.initFOC();

  Serial.println(F("Motor ready."));
  
  setupWiFi();
  delay(2000);
  nh.initNode();
  nh.advertise(chatter);
  nh.subscribe(subjoint);

  delay(100);

  
  Serial.println(F("Set the target velocity using serial terminal:"));

  _delay(1000);
}
 
void loop() {
  str_msg.data = hello;
  chatter.publish( &str_msg );
  nh.spinOnce();
  delay(5);
}

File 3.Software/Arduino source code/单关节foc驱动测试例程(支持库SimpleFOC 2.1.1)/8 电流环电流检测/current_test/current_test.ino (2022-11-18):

// Deng's FOC 开环位置控制例程 测试库：SimpleFOC 2.1.1 测试硬件：灯哥开源FOC V1.0
// 串口中输入"T+数字"设定两个电机的位置，如设置电机转到到180度，输入 "T3.14"（弧度制的180度）
// 在使用自己的电机时，请一定记得修改默认极对数，即 BLDCMotor(7) 中的值，设置为自己的极对数数字
// 程序默认设置的供电电压为 7.4V,用其他电压供电请记得修改 voltage_power_supply , voltage_limit 变量中的值
//               FOC_0.2  Baize_Foc
// IN1     pwm1     9        17
// IN2     pwm2     6        18
// IN3     pwm3     5        19
// INH1   enable1   8        21
// INH2   enable2   7        22
// INH3   enable3   4        23
// 电机极对数:11            减速比:11
//in-line current sense - phase 1/A 35
//in-line current sense - phase 1/C 34
// ESP32  iic接口  SCL:26   SDA:25
// AS5600 iic地址: 0x36
//I2Cone.begin(sda, scl, frequency); 

/**
   使用电压控制回路的扭矩控制示例。
   大多数低端无刷电机驱动器没有电流测量功能，因此SimpleFOC为您提供了一种通过设置电机电压而不是电流来控制电机扭矩的方法。
   这使无刷直流电机有效地成为直流电机，您可以以相同的方式使用它。
*/
// IN1     pwm1    9  27
// IN2     pwm2    6  26
// IN3     pwm3    5  25
// INH1   enable1  8  12
// INH2   enable2  7  13
// INH3   enable3  4  14
//in-line current sense - phase 1/A 35
//in-line current sense - phase 1/C 34
 
#include <SimpleFOC.h>
 
class LowPassFilte {
  public:
    LowPassFilte(float Tf);//低通滤波器时间常量
    ~LowPassFilte() = default;
    float operator() (float x);
    float Tf; //!< 低通滤波器时间常量
  protected:
    unsigned long timestamp_prev;  //!< 上次执行时间戳
    float y_prev; //!< 经过上次执行后过滤到的值
};
 
LowPassFilte::LowPassFilte(float time_constant)
  : Tf(time_constant)
  , y_prev(0.0f)
{
  timestamp_prev = micros();
}
 
float LowPassFilte::operator() (float x)
{
  unsigned long timestamp = micros();
  float dt = (timestamp - timestamp_prev) * 1e-6f;
 
  if (dt < 0.0f || dt > 0.5f)
    dt = 1e-3f;
 
  float alpha = Tf / (Tf + dt);
  float y = alpha * y_prev + (1.0f - alpha) * x;
 
  y_prev = y;
  timestamp_prev = timestamp;
  return y;
}
 
LowPassFilte LF_a(0.01);//原始数据滤波器
LowPassFilte LF_b(0.01);//A相电流滤波器
LowPassFilte LF_c(0.01);//C相电流滤波器
 
 
//AS5600编码器支持spi，iic和模拟量三种数据传输方式，这里用iic（同时也是最常用的方式）
// magnetic sensor instance - I2C
MagneticSensorI2C sensor = MagneticSensorI2C(AS5600_I2C);
TwoWire I2Cone = TwoWire(0);
 
// BLDC motor & driver instance
BLDCMotor motor = BLDCMotor(11);
BLDCDriver3PWM driver = BLDCDriver3PWM(17, 18, 19, 21, 22, 23);
 
 
InlineCurrentSense Cs_motor(0.001, 50.0, 35, 36, 34);
 
// voltage set point variable
float target_voltage = 5.0;
// instantiate the commander
Commander command = Commander(Serial);
void doTarget(char* cmd) {
  command.scalar(&target_voltage, cmd);
}
 
void setup() {
  // initialise magnetic sensor hardware
  I2Cone.begin(25, 26, 400000);
  sensor.init(&I2Cone);
  // link the motor to the sensor
  motor.linkSensor(&sensor);
 
  // power supply voltage
  driver.voltage_power_supply = 12;
  driver.init();
  motor.linkDriver(&driver);
 
  // aligning voltage
  motor.voltage_sensor_align = 5;
  // choose FOC modulation (optional)
  motor.foc_modulation = FOCModulationType::SpaceVectorPWM;
  // set motion control loop to be used
  motor.controller = MotionControlType::torque;
 
  // use monitoring with serial
  Serial.begin(115200);
  // comment out if not needed
  motor.useMonitoring(Serial);
 
  // initialize motor
  motor.init();
  // align sensor and start FOC
  motor.initFOC();
 
  // add target command T
  command.add('T', doTarget, "target voltage");
 
  Serial.println(F("Motor ready."));
  Serial.println(F("Set the target voltage using serial terminal:"));
  _delay(1000);
 
  Cs_motor.init();
}
 
void loop() {
 
  // main FOC algorithm function
  // the faster you run this function the better
  // Arduino UNO loop  ~1kHz
  // Bluepill loop ~10kHz
  motor.loopFOC();
 
  // Motion control function
  // velocity, position or voltage (defined in motor.controller)
  // this function can be run at much lower frequency than loopFOC() function
  // You can also use motor.move() and set the motor.target in the code
  motor.move(target_voltage);
 
 
  // Cs_motor.getPhaseCurrents();
//  Serial.print(LF_b((Cs_motor.getPhaseCurrents()).a));
//  Serial.print(",");
//  Serial.println(LF_c((Cs_motor.getPhaseCurrents()).c));
 
//  Serial.print(LF_a(analogRead(35)));
//  Serial.print(",");
  Serial.print(LF_b((3.3 * ((float)analogRead(35) - 1930) / 4096.0) * 20.0));
  Serial.print(",");
  Serial.println(LF_c((-3.3 * ((float)analogRead(34) - 1930) / 4096.0) * 20.0));
 
  // user communication
  command.run();
}

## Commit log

2022-09-22 fisr upload
    [111.SLDPRT, 17-23-4轴承.SLDPRT, 2020铝-70.SLDPRT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]
2022-11-17 增加运动学解算程序
    [HotDog.urdf]
2022-11-17 add a arduino library
2022-11-18 调整文件夹及程序名称
2022-11-23 变更代码文件名
2022-12-01 添加代码
2022-12-01 添加程序固件烧录工具
2023-04-27 添加制作说明
